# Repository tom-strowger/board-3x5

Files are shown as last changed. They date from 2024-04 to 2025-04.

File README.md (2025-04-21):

# Tom's 3x5 board

## Overview
A keyboard built using ergogen etc.  36 keys wireless using the Seeed studio Xiao nRF52840 module.
This keyboard project heavily borrows from a few similar projects
- [triboard](https://github.com/tarneaux/triboard)
- [TOTEM](https://github.com/GEIGEIGEIST/TOTEM)

The main features of my board are:
- Split
- Wireless
- 36 keys: 5 columns x 3 rows + 3 thumb keys on each side
- Cherry MX switches with hotswap socket
- Uses the cheaper/smaller nordic mcu instead of nice nano
- The ergogen project generates two boards and cases (left and right)
  - The boards are not flippable as the battery charger pads on the mcu would not be reachable

## Images

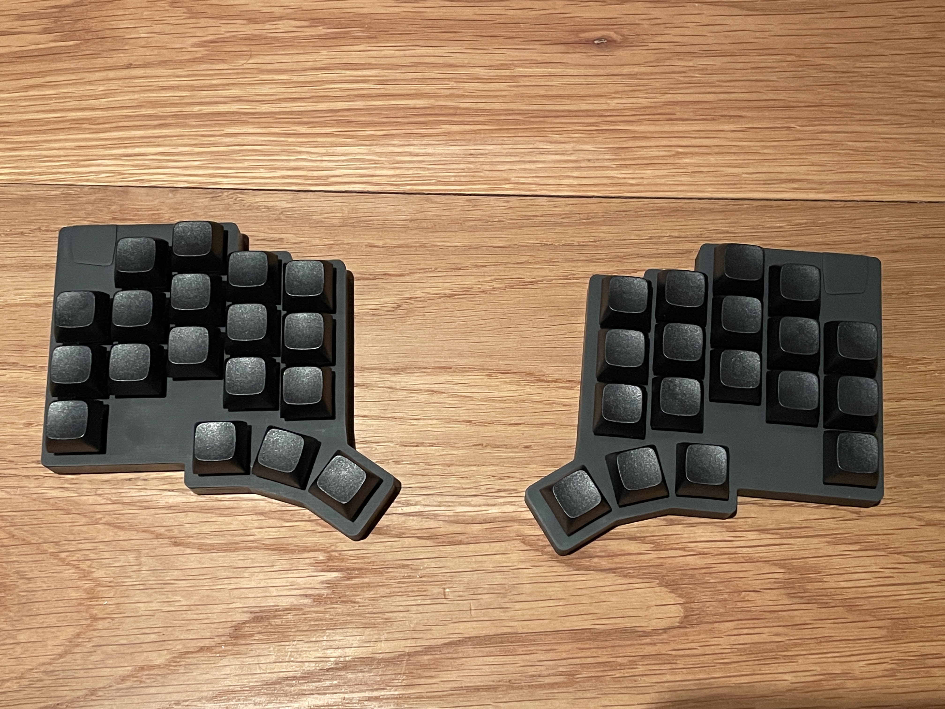
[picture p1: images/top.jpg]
top


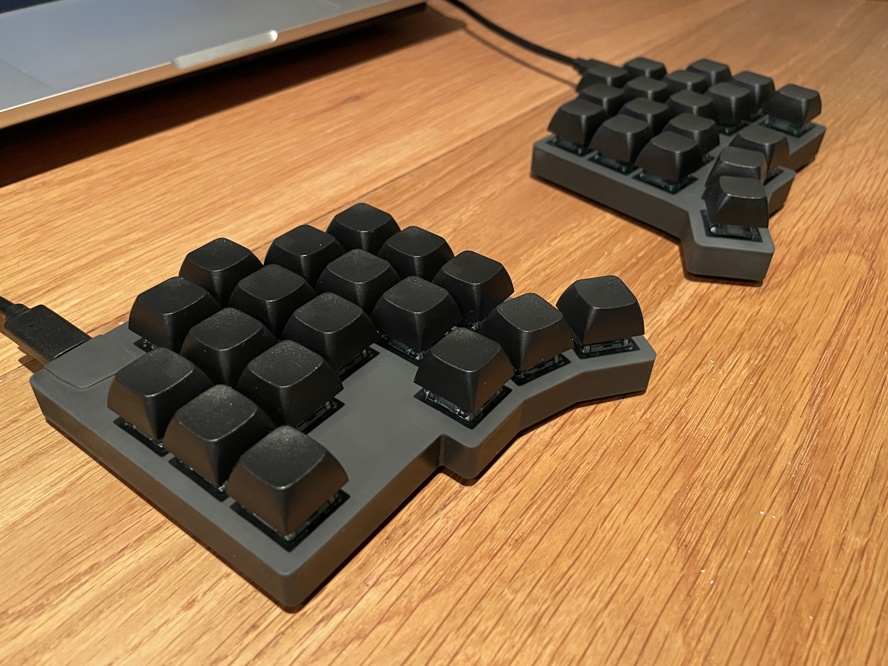
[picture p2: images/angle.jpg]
angle


## Guides
### Prerequisites
- `node` is setup to be run on the system
- For building cases: `npm install @jscad/csg` (this is a deprecated package so must be installed explicitly)

### How to generate the boards
`./build` (watches files and rebuilds when source changes/)

or

`./build once`

### How to generate the cases
`./build cases`

## TODO
- Increase the heat set insert radius as it is set with CA glue insted of being melted in (when printing with SLA resin)
- Add a printed part that slots over the switch and fits into the case allowing it to be easily comtrolled

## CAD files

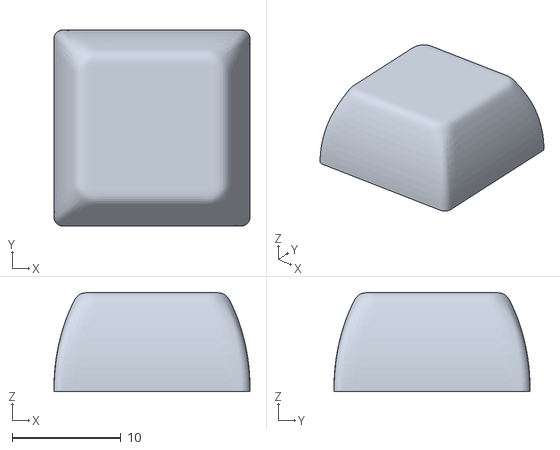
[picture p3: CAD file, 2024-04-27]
3d models/XDA STL.stl
18.0 x 18.0 x 9.10

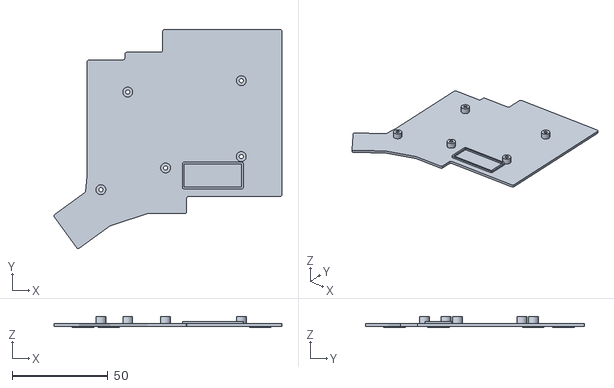
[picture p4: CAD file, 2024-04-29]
output/cases/bottom_case_r.stl
119.1 x 114.4 x 5.50

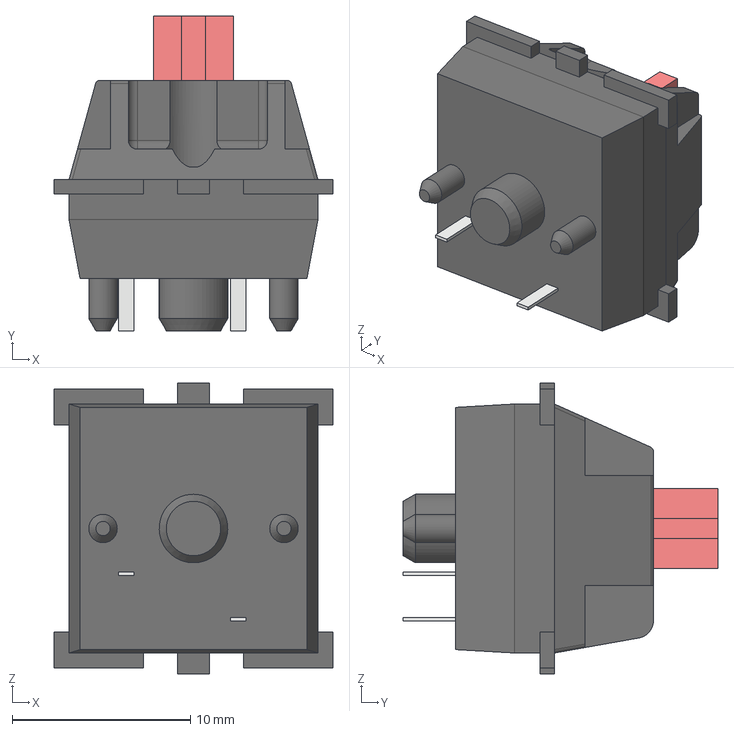
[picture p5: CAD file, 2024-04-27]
3d models/switch.step
15.6 x 17.7 x 16.3 mm

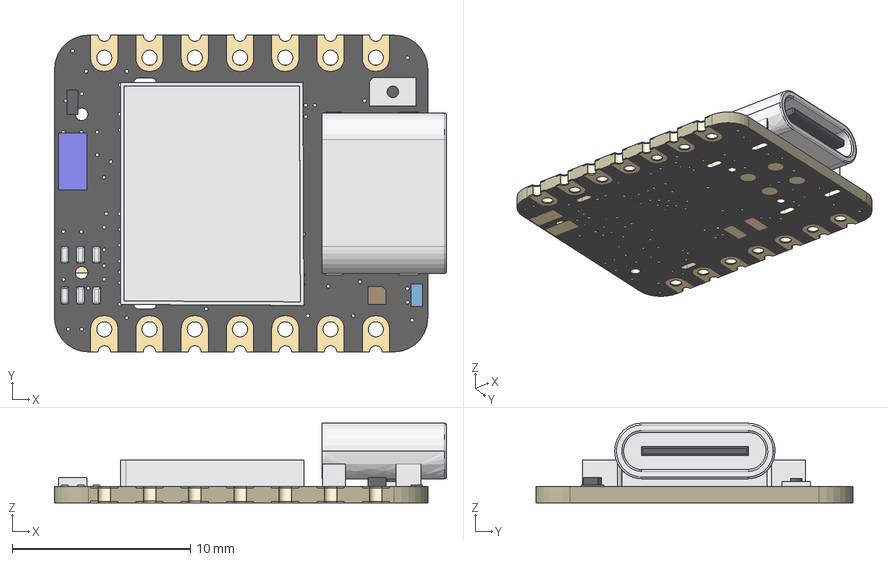
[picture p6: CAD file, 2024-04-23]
3d models/Seeed Studio XIAO nRF52840.step
22.0 x 17.8 x 4.47 mm
EMF Shield
Pins 0-6
Pins 7-13
BAT pads
Unpopulated 6 pin pad
JTAG like thing probably
NFC pads
Board:1
R0201:R1
R0201:R2
R0201:R22
R0201:R31
R0201:R32
R0201:R9
R0201:R3
R0201:R4
R0201:R5
R0201:R6
R0201:R7
R0201:R8
R0201:R10
F0603:F1
C0201:C23
C0201:C39
C0201:C40
C0201:C41
C0201:C42
C0201:C43
C0201:C44
C0201:C45
C0201:C48
C0201:C50
C0201:C53
C0201:C54
C0201:C4
C0201:C1
C0201:C2
C0201:C3
C0201:C5
C0201:C6
C0201:C7
C0201:C8
C0201:C9
C0201:C10
C0201:C11
C0201:C12
C0201:C13
C0201:C14
C0201:C49
C0201:C15
R0201:R21
LED-0402:CHG
QFN32G-0.5-5X5MM:U4
X4-SMD-2.0X1.6X0.5MM:X4
L0201:L1
L0201:L3
PMOS_1.0*0.6*0.35MM:Q1
SOD-523:D1
X2-SMD-1.6X1.0X0.5MM:X2
SOT-25:U2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

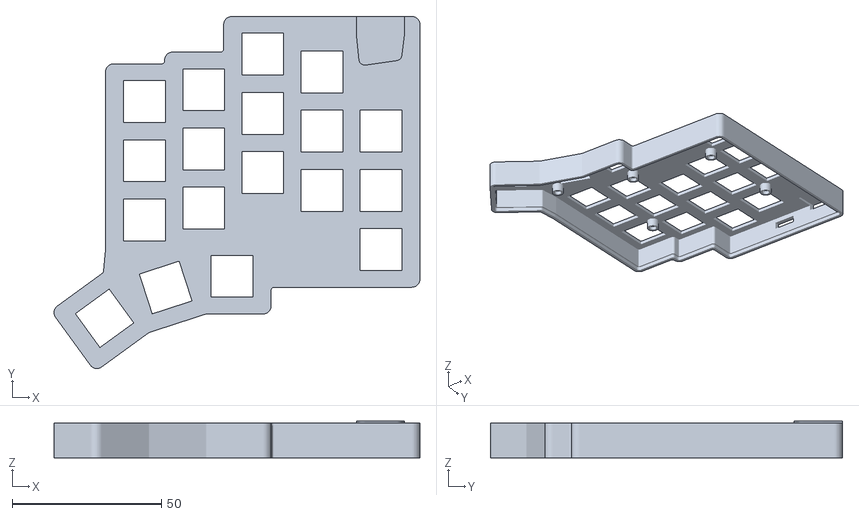
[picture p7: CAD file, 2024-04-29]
output/cases/top_case_r.stl
122.4 x 117.8 x 12.3

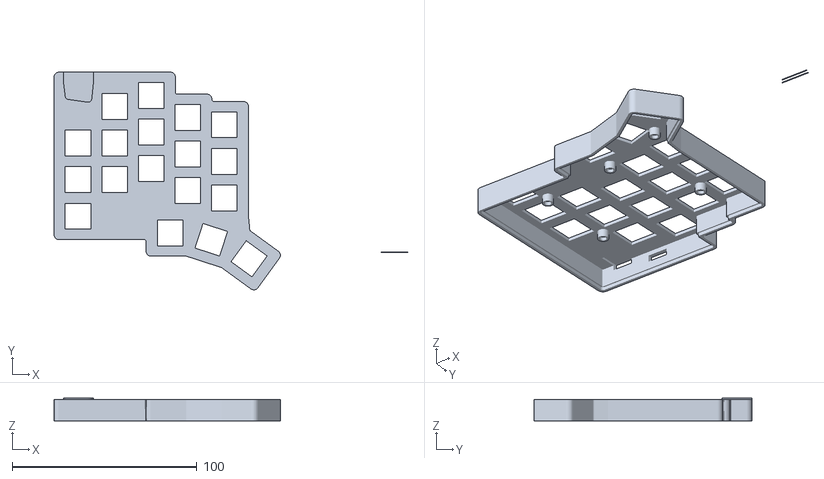
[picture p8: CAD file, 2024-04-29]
output/cases/top_case_l.stl
191.5 x 117.8 x 12.3

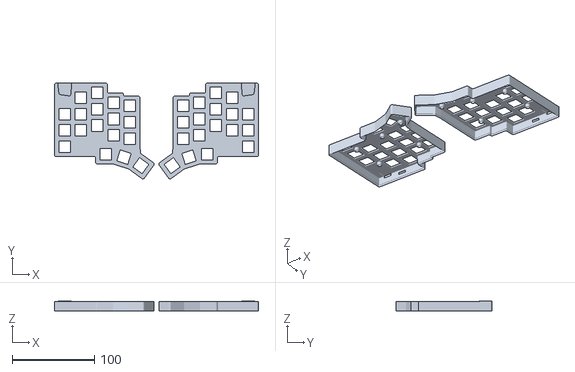
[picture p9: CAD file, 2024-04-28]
output/cases/top_case.stl
247.7 x 116.4 x 12.3

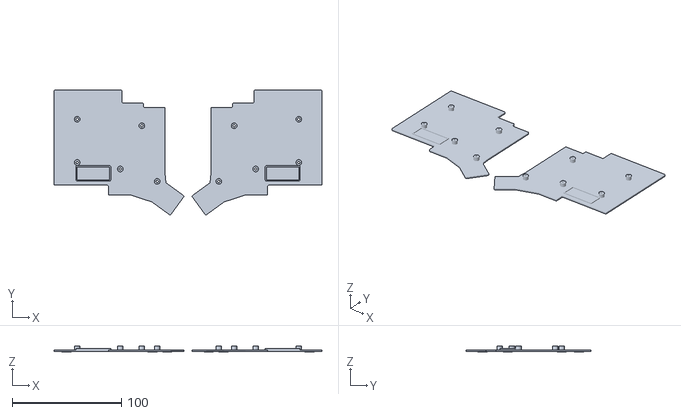
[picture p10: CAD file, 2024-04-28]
output/cases/bottom_case.stl
245.7 x 114.4 x 5.50

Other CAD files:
output/cases/bottom_case_l.stl
3d models/switch.stl

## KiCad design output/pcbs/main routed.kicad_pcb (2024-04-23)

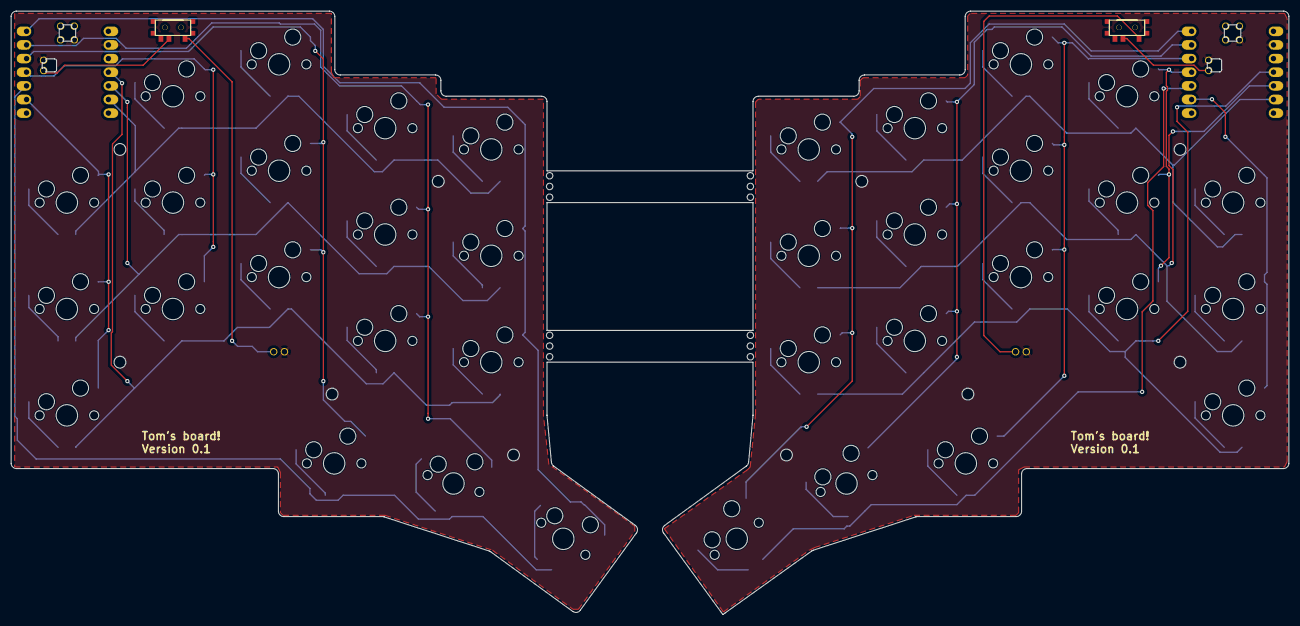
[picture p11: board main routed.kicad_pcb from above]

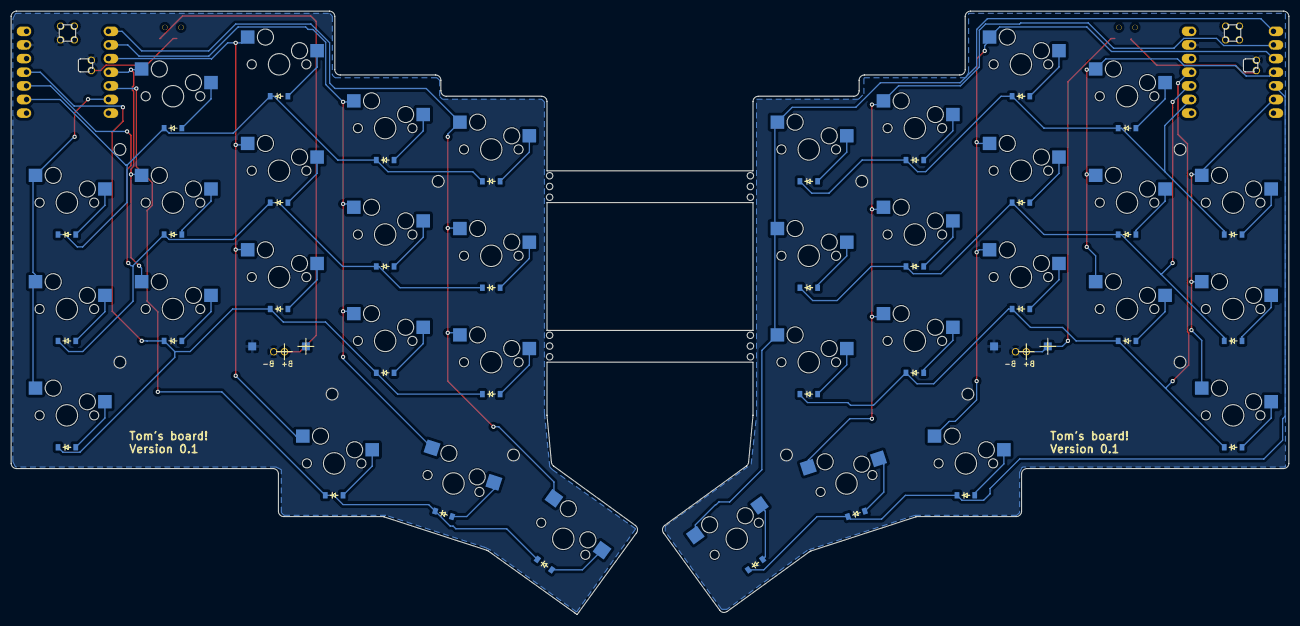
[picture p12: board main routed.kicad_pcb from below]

Board: 2 copper layers, 238.0 x 112.4 mm, 80 parts (36 on the bottom side), 60 nets.

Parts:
BATTPAD1, BATTPAD2, BATTPAD3, BATTPAD4: ComboDiode
D1, D2, D3, D4, D5, D6, D7, D8, D9, D10, D11, D12, D13, D14, D15, D16, D17, D18, D19, D20, D21, D22, D23, D24, D25, D26, D27, D28, D29, D30, D31, D32, D33, D34, D35, D36: ComboDiode
S1, S2, S3, S4, S5, S6, S7, S8, S9, S10, S11, S12, S13, S14, S15, S16, S17, S18, S19, S20, S21, S22, S23, S24, S25, S26, S27, S28, S29, S30, S31, S32, S33, S34, S35, S36: MX
T1, T2: SPDT_C128955
xiao-ble1, xiao-ble2: xiao-ble-thruhole; xiao-ble-smd-cutout

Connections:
L_BAT+: BATTPAD1.1, BATTPAD2.1, T1.1
L_GND: BATTPAD1.2, BATTPAD2.2, xiao-ble1.13, xiao-ble1.18, xiao-ble1.20
L_P0: S13.2, S14.2, S15.2, S18.2, xiao-ble1.1
L_P1: S10.2, S11.2, S12.2, S17.2, xiao-ble1.2
L_P2: S7.2, S8.2, S9.2, S16.2, xiao-ble1.3
L_P3: S4.2, S5.2, S6.2, xiao-ble1.4
L_P4: D16.1, D17.1, D18.1, xiao-ble1.5
L_P5: S1.2, S2.2, S3.2, xiao-ble1.6
L_P8: D3.1, D6.1, D9.1, D12.1, D15.1, xiao-ble1.9
L_P9: D2.1, D5.1, D8.1, D11.1, D14.1, xiao-ble1.10
L_P10: D1.1, D4.1, D7.1, D10.1, D13.1, xiao-ble1.11
L_RAW: T1.2, xiao-ble1.19
R_BAT+: BATTPAD3.1, BATTPAD4.1, T2.1
R_GND: BATTPAD3.2, BATTPAD4.2, xiao-ble2.13, xiao-ble2.18, xiao-ble2.20
R_P0: S31.2, S32.2, S33.2, S36.2, xiao-ble2.1
R_P1: S28.2, S29.2, S30.2, S35.2, xiao-ble2.2
R_P2: S25.2, S26.2, S27.2, S34.2, xiao-ble2.3
R_P3: S22.2, S23.2, S24.2, xiao-ble2.4
R_P4: D34.1, D35.1, D36.1, xiao-ble2.5
R_P5: S19.2, S20.2, S21.2, xiao-ble2.6
R_P8: D21.1, D24.1, D27.1, D30.1, D33.1, xiao-ble2.9
R_P9: D20.1, D23.1, D26.1, D29.1, D32.1, xiao-ble2.10
R_P10: D19.1, D22.1, D25.1, D28.1, D31.1, xiao-ble2.11
R_RAW: T2.2, xiao-ble2.19
home_thumb: D18.2, S18.1
index_bottom: D10.2, S10.1
index_home: D11.2, S11.1
index_top: D12.2, S12.1
inner_bottom: D13.2, S13.1
inner_home: D14.2, S14.1
inner_thumb: D16.2, S16.1
inner_top: D15.2, S15.1
middle_bottom: D7.2, S7.1
middle_home: D8.2, S8.1
middle_thumb: D17.2, S17.1
middle_top: D9.2, S9.1
mirror_home_thumb: D36.2, S36.1
mirror_index_bottom: D28.2, S28.1
mirror_index_home: D29.2, S29.1
mirror_index_top: D30.2, S30.1
mirror_inner_bottom: D31.2, S31.1
mirror_inner_home: D32.2, S32.1
mirror_inner_thumb: D34.2, S34.1
mirror_inner_top: D33.2, S33.1
mirror_middle_bottom: D25.2, S25.1
mirror_middle_home: D26.2, S26.1
mirror_middle_thumb: D35.2, S35.1
mirror_middle_top: D27.2, S27.1
mirror_pinky_bottom: D19.2, S19.1
mirror_pinky_home: D20.2, S20.1
mirror_pinky_top: D21.2, S21.1
mirror_ring_bottom: D22.2, S22.1
mirror_ring_home: D23.2, S23.1
mirror_ring_top: D24.2, S24.1
pinky_bottom: D1.2, S1.1
pinky_home: D2.2, S2.1
pinky_top: D3.2, S3.1
ring_bottom: D4.2, S4.1
ring_home: D5.2, S5.1
ring_top: D6.2, S6.1

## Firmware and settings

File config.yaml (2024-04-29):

units:
  # Size of each key. cx and cy for choc, u and U for MX.
  kx: u
  ky: U
  # key spread and padding
  px: 1.04kx
  py: 1.04ky
  # From that, get the spacing between keys
  ksx: px-kx
  ksy: py-ky
  lpx: px + 1
  
  # Stagger for all of the different columns
  stagger1: py # ring column one key above the pinky column
  stagger2: 0.3py # middle column .3 key above the ring column
  stagger3: -0.6py # index
  stagger4: -0.2py # inner

  # Case space, between pcb and walls
  cs: 0.5
  # Case thickness
  ct: 1.5
  # Wall thickness. This gives 1.5mm when the space is subtracted for the bottom  
  wt: 2.2
  # The amount the bottom overlaps the walls
  bottom_overlap: 0.5
  bottom_case_space: 0.2  # space between bottom case and the inset walls

  pcb_thickness: 1.6
  pcb_space_under: 3.5 # battery is 3mm high
  pcb_space_over: 5.0 - ct  # 3.5

  xiao_length: 21
  xiao_width: 17.78

  screw_radius: 1.1
  screw_bore_outer_radius: 2.6
  screw_head_insert_radius: 1.8  # M2 head diameter = 3mm
  screw_head_insert_depth: 1.3 # M2 head height = 1.1mm
  heat_set_radius_inner: 1.5 # Inner diameter for M2xL2xOD3.2
  heat_set_radius_outer: 2.5 # Outer diameter for M2xL2xOD3.2

  feet_ring_inner_radius: 4.2  # To fit 8mm diameter feet
  feet_ring_outer_radius: 5.7
  feet_ring_height: 0.5

  battery_width: 12.0
  battery_length: 30.0


points:
  key:
    spread: 1px
    padding: 1py
  zones:
    matrix:
      columns:
        pinky:
          key:
            column_net: "L_P5"
          key.mirror:
            column_net: "R_P5"
        ring:
          key:
            stagger: stagger1
            column_net: "L_P3"
          key.mirror:
            column_net: "R_P3"
        middle:
          key:
            stagger: stagger2
            column_net: "L_P2"
          key.mirror:
            column_net: "R_P2"
        index:
          key:
            stagger: stagger3
            column_net: "L_P1"
          key.mirror:
            column_net: "R_P1"
        inner:
          key:
            stagger: stagger4
            column_net: "L_P0"
          key.mirror:
            column_net: "R_P0"
      rows:
        bottom:
          row_net: "L_P10"
        bottom.mirror:
          row_net: "R_P10"
        home:
          row_net: "L_P9"
        home.mirror:
          row_net: "R_P9"
        top:
          row_net: "L_P8"
        top.mirror:
          row_net: "R_P8"
    thumbfan:
      anchor:
        ref: matrix_index_bottom
        shift: [-kx/2, -py-3]
      columns:
        inner:
          key:
            column_net: "L_P2"
            splay: 0
          key.mirror:
            column_net: "R_P2"
        middle:
          key:
            column_net: "L_P1"
            splay: -18
            adjust.shift: [3.5, -2.8]
          key.mirror:
            column_net: "R_P1"
        home:
          key:
            column_net: "L_P0"
            splay: -18
            adjust.shift: [8, -4]
          key.mirror:
            column_net: "R_P0"
      rows:
        thumb:
          row_net: "L_P4"
        thumb.mirror:
          row_net: "R_P4"
  mirror: &mirror
    ref: thumbfan_home_thumb
    distance: 2kx

outlines:

  battery_border_inner_l:
    -   what: rectangle
        adjust:
          ref: matrix_ring_bottom
          shift: [0.25px, -py]
        size: [battery_length, battery_width]
  battery_border_outer_l:
    -   what: outline
        name: battery_border_inner_l
        expand: 1
  battery_border_l:
    - what: outline
      name: battery_border_outer_l
      operation: add
    - what: outline
      name: battery_border_inner_l
      operation: subtract
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

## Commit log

2024-04-17 Initial board
    Lots borrow from other ergogen repos
    - https://github.com/tarneaux/triboard.git
    - https://github.com/Narkoleptika/josukey/
2024-04-21 Added breaks, battery thru hole, shift mcu up a touch to edge
2024-04-21 Fix diode layers
2024-04-23 Outputs from first version, routed
    [Seeed Studio XIAO nRF52840.step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]
2024-04-23 Working on the case - WIP
2024-04-23 Working on bottom case
2024-04-25 The cases join cleaner, confirmed spacing of usb conn and switch
    [bottom_case.stl, top_case.stl]
2024-04-27 Add heat set nuts, feet rings, usb reinforcement, centre switch gap
    [XDA STL.stl, switch.step, switch.stl]
2024-04-27 Added battery holder underneath, increased het set size
2024-04-27 Case output, first version
    [bottom_case.stl, top_case.stl]
2024-04-27 Split case, add battery holder to right
2024-04-28 Add walls to top, bottom sits on walls, increase usb tolerance
    This is being sent to manufacture
    [bottom_case.stl, bottom_case_l.stl, bottom_case_r.stl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]
2024-04-29 Increase feet ring width to 1.5mm
    This is to meet manufacturing requirements
    [bottom_case_l.stl, bottom_case_r.stl]
2024-04-29 Increase wall thickness so they are 1.5mm at the thinnest
    [bottom_case_l.stl, bottom_case_r.stl, top_case_l.stl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]
2024-05-08 Track jpg with git lfs
2024-05-08 Remove extra cases from root dir
    [bottom_case.stl, top_case.stl]
